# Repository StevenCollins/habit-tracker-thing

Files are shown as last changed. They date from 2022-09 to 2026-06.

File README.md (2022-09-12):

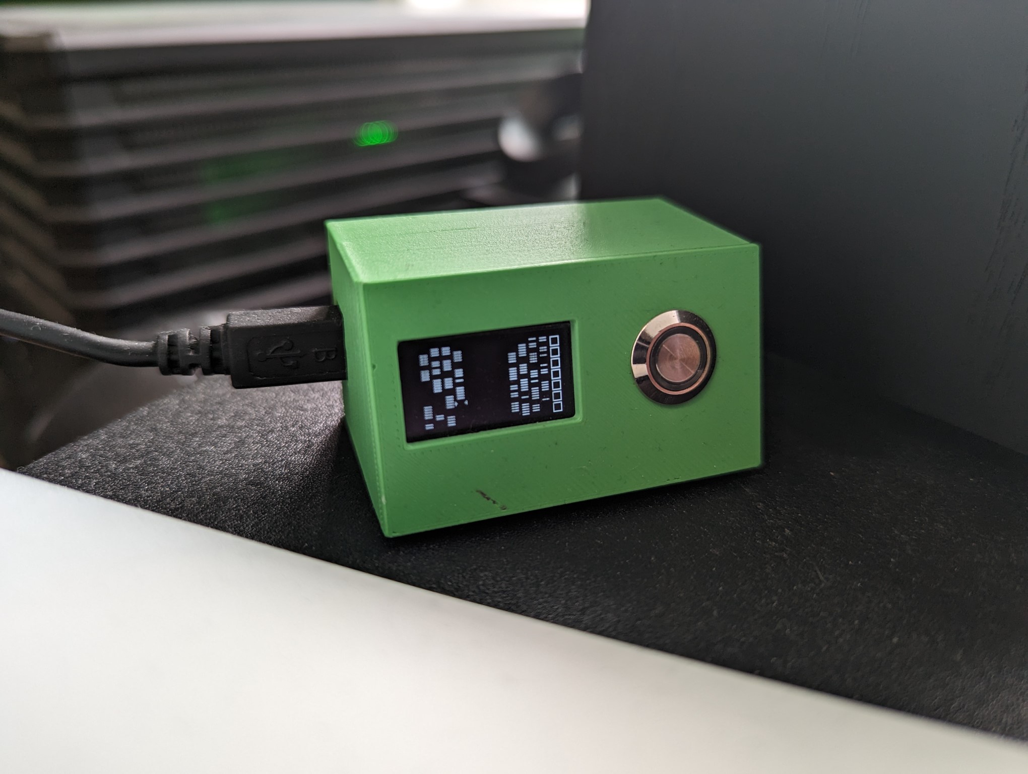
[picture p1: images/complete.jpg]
a photo of the complete habit tracker thing


# habit tracker thing
A daily habit tracker built on the ESP32. If you do the thing you want to make a habit of, you get to push the button!

Pushing the button makes a little line representing the day show up on the screen. The screen shows 12 columns, each representing a month, making up a full year. The current week (Sun to Sat) is also displayed. See `screen-reference.png` to see the layout.

Optionally, the button can be made active only within a certain period so if the habit you want is "complete [your habit] before [a specific time]" you have to hit the button before that time. While the button is active the green LED is lit.

The habit tracker thing is connected to WiFi for the time. WiFi credentials can be added in the main `habit-tracker-thing.ino` file or in `WiFiSettings.h`.

To build the habit tracker thing you'll need an ESP32, a SSD1306 display, a button, an LED, and a resistor. To fully complete the project you'll also need some soldering skills and a 3D printer. Files for the enclosure are available on [Printables](https://www.printables.com/model/274829-habit-tracker-thing-enclosure).

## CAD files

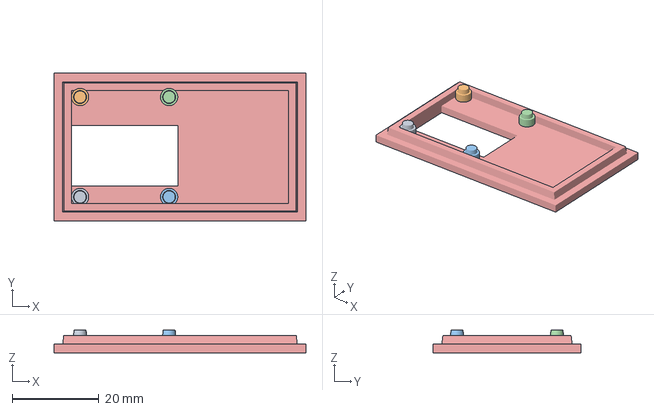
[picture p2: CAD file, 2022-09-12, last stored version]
3mf/Habit Tracker Front.3mf
58.0 x 34.0 x 5.20 mm

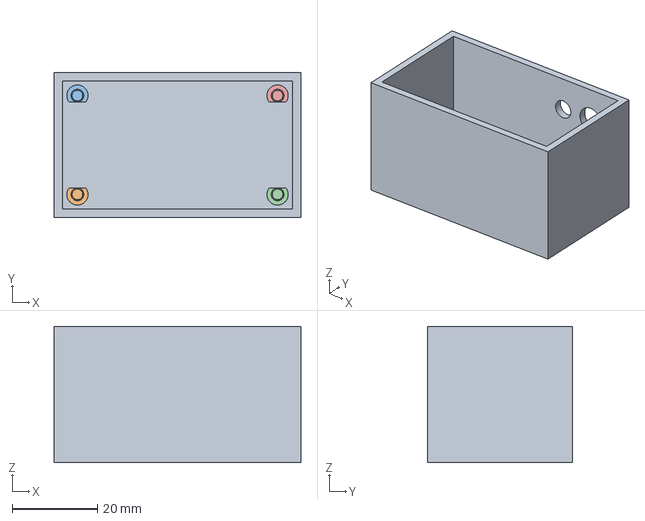
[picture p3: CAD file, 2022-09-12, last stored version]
3mf/Habit Tracker Back.3mf
58.0 x 34.0 x 32.0 mm

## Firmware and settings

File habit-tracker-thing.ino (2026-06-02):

/*
  Board: DOIT ESP32 DEVKIT V1
  Screen API: https://github.com/ThingPulse/esp8266-oled-ssd1306 "ESP8266 and ESP32 Oled Driver for SSD1306 display"
  Time Docs: https://github.com/Patapom/Arduino/blob/master/Libraries/AVR%20Libc/avr-libc-2.0.0/include/time.h
  Screen layout: ./screen-reference.png
*/

/*
    To Do:
  Make data available on web server
  Allow updating valid time on web server
  Allow inputting the habit to be tracked and other notes through the webserver
  Store valid time in preferences
  Make end of month visible on "calendar" using (animated?) background
    Unchecked days will cover background making month ends visible
*/

#include <WiFi.h>
#include <time.h>
#include <esp_sntp.h>
#include "WiFiSettings.h"
#include <Wire.h>
#include <SSD1306Wire.h> // From https://github.com/ThingPulse/esp8266-oled-ssd1306
#include <Preferences.h>

#ifndef STASSID
#define STASSID "your-ssid"
#define STAPSK  "your-password"
#endif

#define SDA 14
#define SCL 27
#define LED 26
#define BUTTON 25
#define ONE_DAY 86400

SSD1306Wire display(0x3c, SDA, SCL);
Preferences preferences;

const char* timeZone = "EST5EDT,M3.2.0,M11.1.0";
const char* ntpServer1 = "pool.ntp.org";
const char* ntpServer2 = "time.nist.gov";

const char* ssid = STASSID;
const char* password = STAPSK;

const int width = 6; // Width of month column
const int height = 2; // Height of each day in a month column
const int border = 1; // Space to edge of screen
const int columnSpace = 3; // Space between columns
const int weekSize = 8; // Size of each week box
const int weekSpace = 1; // Space between week boxes

const int oledBrightness = 32; // Brightness (0-255)
const int oledMaxShift = 10; // Maximum number of pixels to shift display
const int oledShiftPeriod = 60000; // How long between shifts (in ms)
unsigned long oledLastShiftTime = 0; // Time of last shift
bool oledShiftDirection = true;  // Which direction we're currently shifting (true is right)
int oledShiftAmount = 0; // Current shift amount
bool oledShiftY = false; // Shifts Y by 1

const int debounceDelay = 50;
unsigned long lastDebounceTime = 0;
int lastButtonState = LOW;
int buttonState;
bool buttonActive = true;
bool trackButtonState = false;

const int timeCheckPeriod = 1000;
unsigned long lastTimeCheck = 0;
struct tm timeInfo;
/* Set active button time here */
int validTimeStartHour = 6; // The hour to allow activating the button, 0 is midnight, up to 23 for 11pm
int validTimeStartMinute = 0; // The minute to allow activating the button
int validTimeEndHour = 9; // The hour to disable the button
int validTimeEndMinute = 30; // The minute to disable the button
/* Set active button time here */
int validTimeStart() { return validTimeStartHour * 60 + validTimeStartMinute; } // Start time in minutes past midnight
int validTimeEnd() { return validTimeEndHour * 60 + validTimeEndMinute; } // End time in minutes past midnight

bool habitData[12][31];

void setup() {
  Serial.begin(115200);

  pinMode(BUTTON, INPUT_PULLUP);
  pinMode(LED, OUTPUT);
  digitalWrite(LED, buttonActive); // LED and button status must start the same

  configTzTime(timeZone, ntpServer1, ntpServer2);

  display.init();
  display.setBrightness(oledBrightness);
  display.flipScreenVertically();

  WiFi.begin(ssid, password);
  display.drawString(0, 0, "Initiating WiFi");
  display.display();
  while (WiFi.status() != WL_CONNECTED) { delay(10); }

  display.drawString(0, 12, "Initiating RTC");
  display.display();
  while (!getLocalTime(&timeInfo)) { delay(10); }

  display.drawString(0, 12, "Loading data");
  display.display();
  if (!preferences.begin("habitData")) {
    display.drawString(0, 24, "ERROR LOADING DATA");
    display.display();
    delay(300000);
  }
  loadHabitData();
  
  displayHabitData();
}

void loop() {
  updateRTC();
  updateButtonStatus();
  checkButton();
  oledPixelShiftUpdate();
  serialInHabitData();

  // Handle habit tracked!
  int month = timeInfo.tm_mon;
  int day = timeInfo.tm_mday - 1;
  if (buttonState == HIGH && buttonActive) {
    updateHabitData(month, day, true);
  }
}

// Draws habit data to the display
void displayHabitData() {
  display.clear();

  // Draw year data
  for (int month = 0; month < 12; month++) {
    for (int day = 0; day < 31; day++) {
      if (habitData[month][day]) {
        int x = month * (width + columnSpace) + border + oledShiftAmount;
        int y = day * height + border + (oledShiftY ? 1 : 0);
        display.fillRect(x, y, width, height - 1);
      }
    }
  }

  // Draw week data
  time_t presentTime = time(NULL); // Get timestamp of current time
  int x = 12 * (width + columnSpace) + border + oledShiftAmount; // All week data is at same x
  for (int dayOfWeek = 0; dayOfWeek < 7; dayOfWeek++) {
    int y = dayOfWeek * (weekSize + weekSpace) + border + (oledShiftY ? 1 : 0);
    if (dayOfWeek < timeInfo.tm_wday) { // Days before today should be checked
      time_t pastTime = presentTime - ((timeInfo.tm_wday - dayOfWeek) * ONE_DAY); // Create timestamp of date to be checked
      struct tm pastTimeInfo;
      localtime_r(&pastTime, &pastTimeInfo); // Convert timestamp to calendar info
      // Check the status of that day, and draw a filled or empty box based on that
      bool habit = habitData[pastTimeInfo.tm_mon][pastTimeInfo.tm_mday - 1];
      habit ? display.fillRect(x, y, weekSize, weekSize) : display.drawRect(x, y, weekSize, weekSize);
    } else if (dayOfWeek == timeInfo.tm_wday) { // Today
      // Check the status of today, and draw a filled or empty box based on that
      bool habit = habitData[timeInfo.tm_mon][timeInfo.tm_mday - 1];
      habit ? display.fillRect(x, y, weekSize, weekSize) : display.drawRect(x, y, weekSize, weekSize);
    } else { // Days after today will always be empty
      display.drawRect(x, y, weekSize, weekSize);
    }
  }
  
  // Mark today
  int xToday = timeInfo.tm_mon * (width + columnSpace) + border + oledShiftAmount;
  int yToday = (timeInfo.tm_mday - 1) * height + border + (oledShiftY ? 1 : 0);
  display.setPixel(xToday - 1, yToday);
  display.fillRect(xToday - 2, yToday - 1, 1, 3);
  display.setPixel(xToday + 6, yToday);
  display.fillRect(xToday + 7, yToday - 1, 1, 3);

  display.display();
}

// Debounces button input
void checkButton() {
  int buttonReading = !digitalRead(BUTTON);
  if (buttonReading != lastButtonState) {
      if (trackButtonState) {
        Serial.print("Button reading changed: ");
        Serial.println(buttonState ? "Pressed" : "Not pressed");
      }
      lastDebounceTime = millis();
  }
  if ((millis() - lastDebounceTime) > debounceDelay) {
    if (buttonReading != buttonState) {
        buttonState = buttonReading;
        if (trackButtonState) {
          Serial.print("Button status changed: ");
          Serial.println(buttonState ? "Pressed" : "Not pressed");
        }
    }
  }
  lastButtonState = buttonReading;
}

// Updates the RTC
void updateRTC() {
  if ((millis() - lastTimeCheck) > timeCheckPeriod) {
    lastTimeCheck = millis();
    getLocalTime(&timeInfo);
  }
}

// Activiates or deactivates the button based on current status, time, and habit data
void updateButtonStatus() {
  int currentMinutesPastMidnight = timeInfo.tm_hour * 60 + timeInfo.tm_min;
  bool timeValid = currentMinutesPastMidnight >= validTimeStart() && currentMinutesPastMidnight <= validTimeEnd();

  if (!buttonActive && !habitData[timeInfo.tm_mon][timeInfo.tm_mday - 1] && timeValid) {
    // Button is not active and should be (habit not tracked and valid time)
    buttonActive = true;
    digitalWrite(LED, HIGH);
  } else if (buttonActive && (habitData[timeInfo.tm_mon][timeInfo.tm_mday - 1] || !timeValid)) {
    // Button is active and should not be (habit tracked or invalid time)
    buttonActive = false;
    digitalWrite(LED, LOW);
  }
}

// Periodically shifts pixels to save the OLED screen
void oledPixelShiftUpdate() {
  if ((millis() - oledLastShiftTime) > oledShiftPeriod) {
    oledLastShiftTime = millis();
    oledShiftAmount += oledShiftDirection ? 1 : -1;
    if (oledShiftAmount >= oledMaxShift) {
      oledShiftDirection = !oledShiftDirection;
    } else if (oledShiftAmount <= 0) {
      oledShiftDirection = !oledShiftDirection;
      oledShiftY = !oledShiftY;
    }
  }
  displayHabitData();
}

// Use this function to make changes to habit data
// Only this function and loadHabitData should modify the habitData object
void updateHabitData(int month, int day, bool status) {
  habitData[month][day] = status;
  saveHabitData(month, day, status);
  displayHabitData();
}

//
// Preferences functions
//

// Loads habitData from Preferences
void loadHabitData() {
  char key[6];
  for (int month = 0; month < 12; month++) {
    for (int day = 0; day < 31; day++) {
      snprintf(key, 6, "%d-%d", month, day);
      habitData[month][day] = preferences.getBool(key);
    }
  }
}

// Saves habitData from Preferences
void saveHabitData(int month, int day, bool status) {
  char key[6];
  snprintf(key, 6, "%d-%d", month, day);
  preferences.putBool(key, status);
}

//
// Test functions
//

// Test function - checks habitData variable against Preferences
bool checkHabitData() {
  char key[6];
  for (int month = 0; month < 12; month++) {
    for (int day = 0; day < 31; day++) {
      snprintf(key, 6, "%d-%d", month, day);
      if (habitData[month][day] != preferences.getBool(key)) {
        return false;
      }
    }
  }
  return true;
}

// Test function - outputs habitData over serial
void serialOutHabitData() {
  for (int month = 0; month < 12; month++) {
    char monthString[32] = "";
    for (int day = 0; day < 31; day++) {
      strlcat(monthString, habitData[month][day] ? "1" : "0", 32);
    }
    Serial.println(monthString);
  }
  Serial.println("-------------------------------");
}

// Test function - allows modifying habitData over serial
void serialInHabitData() {
  while (Serial.available() > 0) {
    int month = Serial.parseInt();
    int day = Serial.parseInt();
    if (Serial.read() == '\n') {
      if (month >= 1 && month <= 12 && day >= 1 && day <= 31) { // m d : Toggle habit data for given day
        updateHabitData(month-1, day-1, !habitData[month-1][day-1]);
      } else if (month == -1 && day == 1) { // -1 1 : Output habit data over serial
        serialOutHabitData();
      } else if (month == -1 && day == 2) { // -1 2 : Check habitData variable against Preferences
        Serial.println("Checking habit data...");
        Serial.println(checkHabitData() ? "Passed" : "Failed");
      } else if (month == -1 && day == 3) { // -1 3 : Output current IP address and time
        Serial.println(WiFi.localIP());
        Serial.println(&timeInfo, "%A, %B %d %Y %H:%M:%S");
        Serial.print("Start/End/Current MPM: ");
        Serial.print(validTimeStart());
        Serial.print("/");
        Serial.print(validTimeEnd());
        Serial.print("/");
        Serial.println(timeInfo.tm_hour * 60 + timeInfo.tm_min);
      } else if (month == -1 && day == 4) { // -1 4 : Output current button status and toggle status change output
        Serial.print("Button status: ");
        Serial.println(buttonState ? "Pressed" : "Not pressed");
        trackButtonState = !trackButtonState;
      } else if (month == -1 && day == 0) { // -1 0 : Clears all data (habitData and Preferences)
        memset(habitData, 0, sizeof(habitData));
        preferences.clear();
        displayHabitData();
      }
    }
  }
}

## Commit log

2022-09-05 Hardware setup complete
    Display, button, LED, WiFi, and RTC setup complete
2022-09-07 Added pixel shifting
    The display is now dimmer and shifted periodically to reduce OLED burn in
    [habit-tracker-thing.ino]
2022-09-07 Button now only active during specified period
    Button is now only active between the specified times,
    LED is only active when the button is active,
    converted some defines to constants
2022-09-09 Fixed valid time calculation
    Also added additional ideas and debug output
    [habit-tracker-thing.ino]
2022-09-09 Improved display of data
    Days are now stripes so it's possible to count them,
    the current date looks different,
    and a Y OLED shift has been added as really only every other line is used now
2022-09-11 Changed pins
    Changed used pins to fit in the case,
    also inverted the button read output because that changed?
    [habit-tracker-thing.ino]
2022-09-12 Readme and enclosure
    Updated the readme with a proper description and image,
    and added enclosure files
    [Habit Tracker Back.3mf, Habit Tracker Front.3mf]
2022-09-12 Removed enclosure files
    Added a link to Printables instead
    [Habit Tracker Back.3mf, Habit Tracker Front.3mf]
2022-09-24 Added button state tracking
    Continuous button state data over serial can be toggled
2025-01-27 Minor maintenance
    Added Arduino IDE library name for screen,
    updated sntp header due to depreciation
